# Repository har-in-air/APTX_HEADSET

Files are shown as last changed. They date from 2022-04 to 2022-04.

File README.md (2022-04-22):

# APTX_HEADSET

Kicad [schematic](aptx_headset.pdf) and PCB layout for an APTX bluetooth audio headset.
* FT-3188 Qualcomm CSR8645 module 
* OPA1664 opamps for differential to single-ended audio conversion, and headphone buffer.
* LM358 buffered virtual ground for single-ended opamp power supply.
* Two layers, 65 mm x 32 mm.

## Top
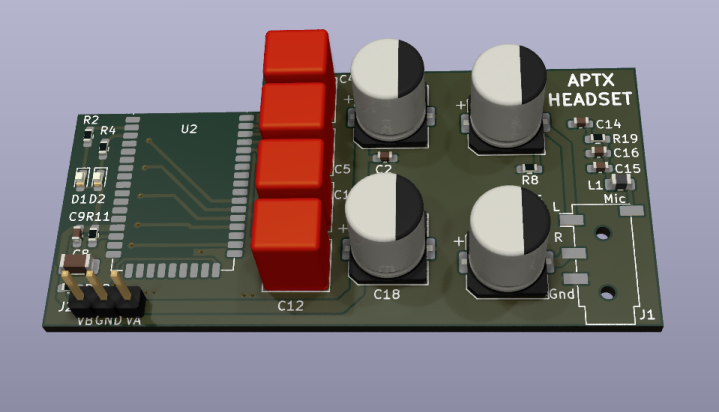
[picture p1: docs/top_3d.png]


## Bottom
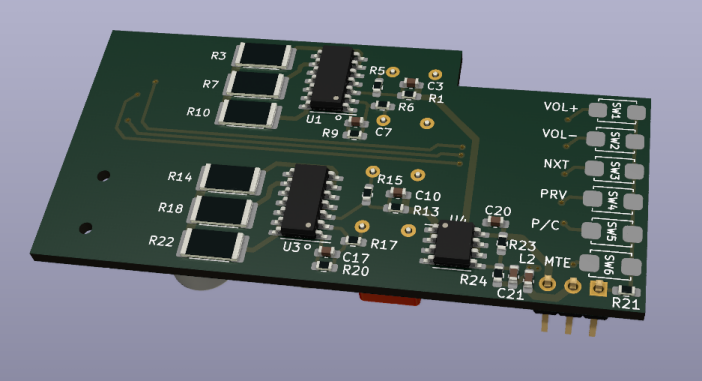
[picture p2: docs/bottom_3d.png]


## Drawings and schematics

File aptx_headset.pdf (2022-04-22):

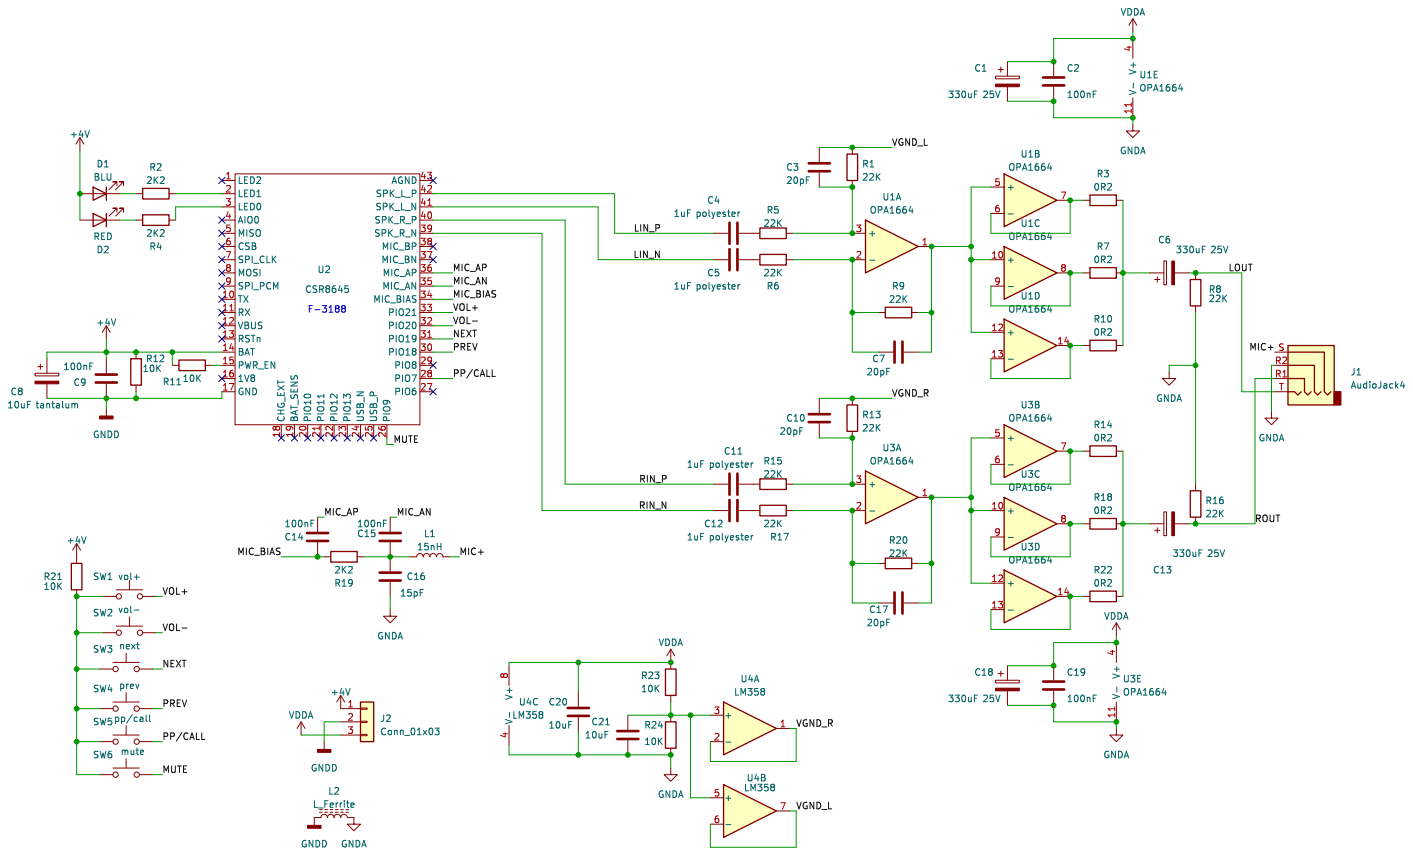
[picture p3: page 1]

4 U3E OPA1664 SW5 pp/call GNDA GNDA R21

PP/CALL MUTE NEXT VOL+ VOL-

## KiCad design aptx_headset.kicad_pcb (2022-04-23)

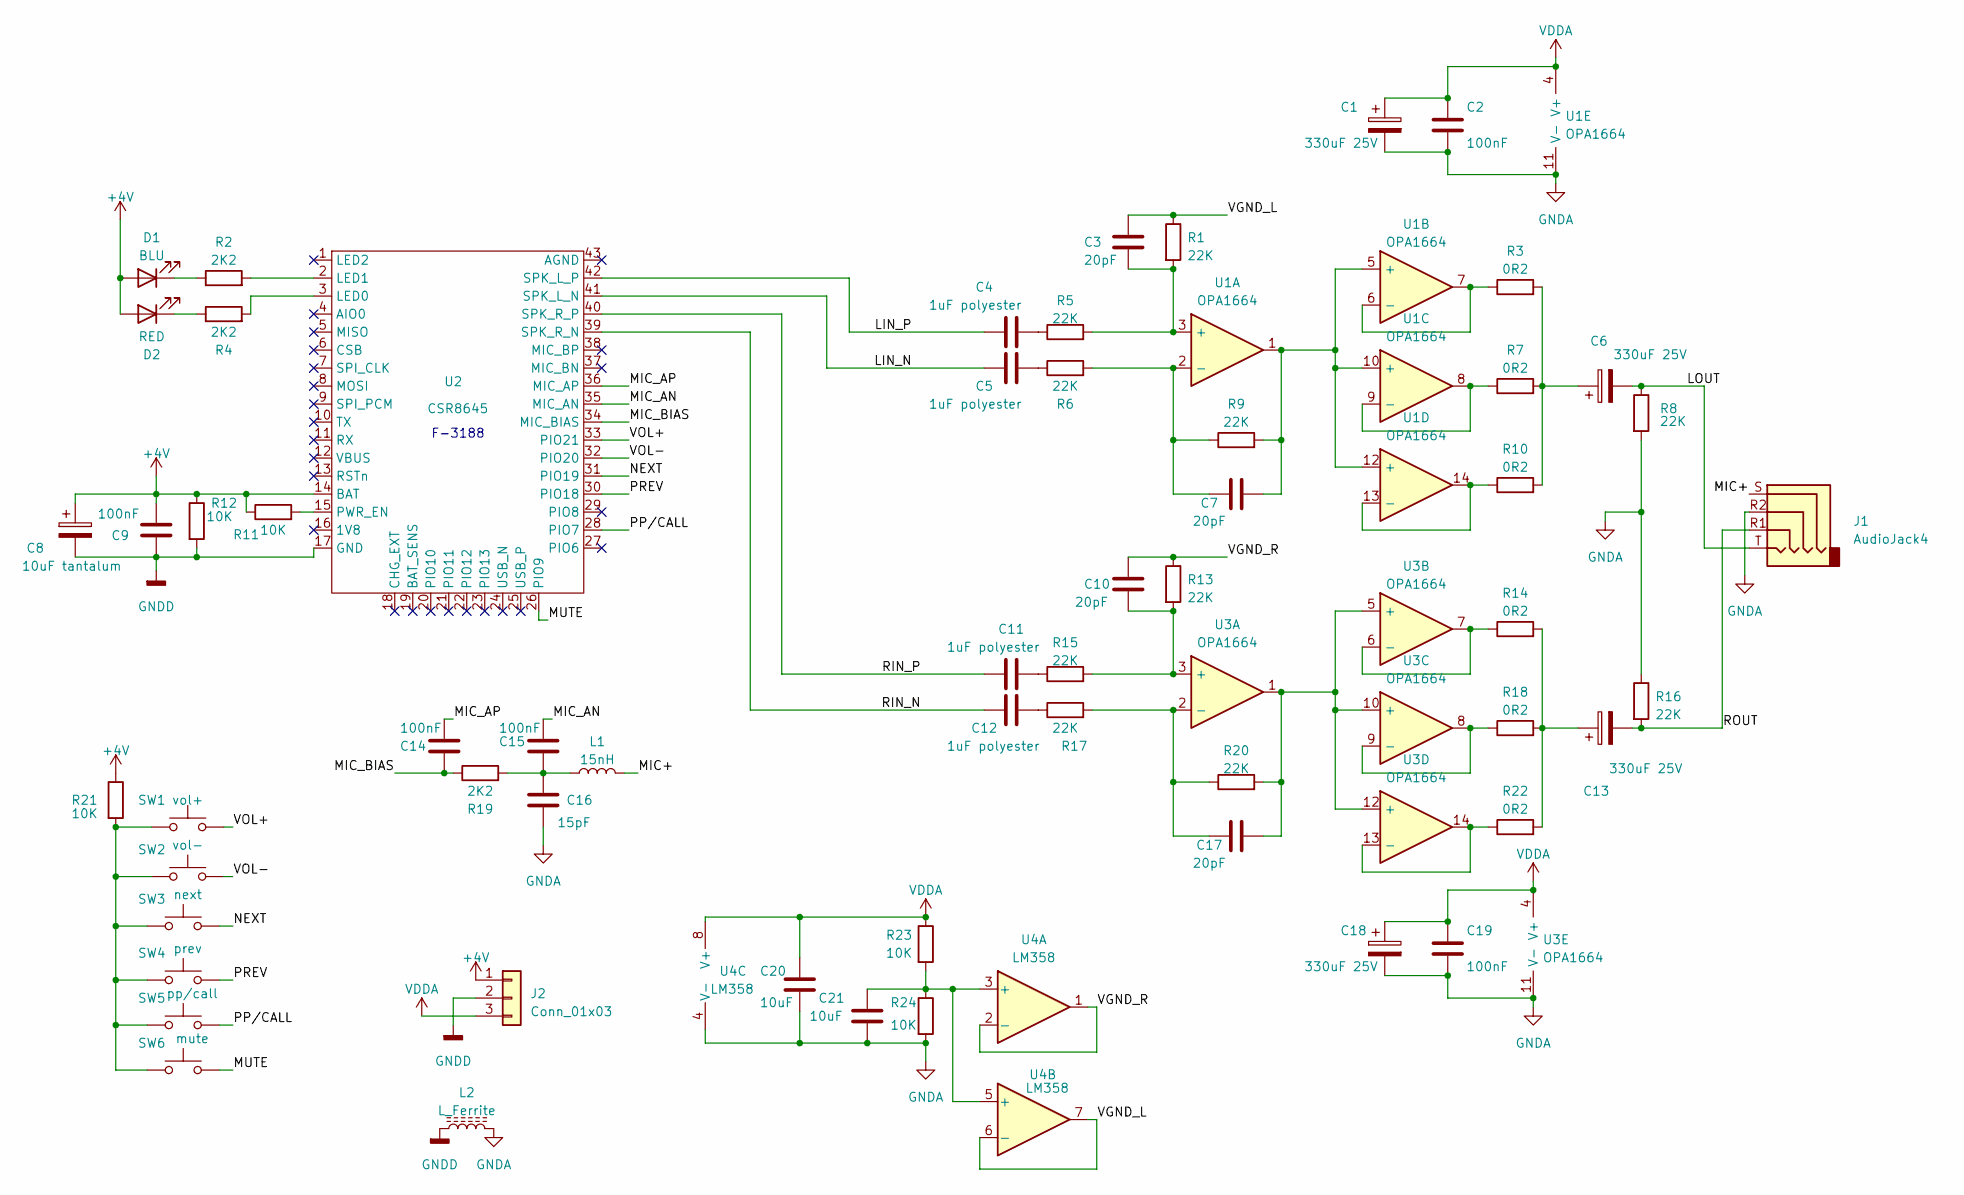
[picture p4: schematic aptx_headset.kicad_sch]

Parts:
C1, C6, C13, C18: 330uF 25V; CP_Elec_8x10
C2, C9, C14, C15, C19: 100nF; C_0603_1608Metric_Pad1.08x0.95mm_HandSolder
C3, C7, C10, C17: 20pF; C_0603_1608Metric_Pad1.08x0.95mm_HandSolder
C4, C5, C11, C12: 1uF polyester; C_Rect_L7.0mm_W6.0mm_P5.00mm
C8: 10uF tantalum; C_1206_3216Metric_Pad1.33x1.80mm_HandSolder
C16: 15pF; C_0603_1608Metric_Pad1.08x0.95mm_HandSolder
C20, C21: 10uF; C_0603_1608Metric_Pad1.08x0.95mm_HandSolder
D1: BLU; LED_0603_1608Metric_Pad1.05x0.95mm_HandSolder
D2: RED; LED_0603_1608Metric_Pad1.05x0.95mm_HandSolder
J1: AudioJack4; Jack_3.5mm_PJ320D_Horizontal
J2: Conn_01x03; PinHeader_1x03_P2.54mm_Vertical
L1: 15nH; L_0805_2012Metric_Pad1.15x1.40mm_HandSolder
L2: L_Ferrite; C_0603_1608Metric_Pad1.08x0.95mm_HandSolder
R1, R5, R6, R8, R9, R13, R15, R16, R17, R20: 22K; R_0603_1608Metric_Pad0.98x0.95mm_HandSolder
R2, R4, R19: 2K2; R_0603_1608Metric_Pad0.98x0.95mm_HandSolder
R3, R7, R10, R14, R18, R22: 0R2; R_2512_6332Metric_Pad1.40x3.35mm_HandSolder
R11, R12, R21, R23, R24: 10K; R_0603_1608Metric_Pad0.98x0.95mm_HandSolder
SW1: vol+; SW_Push_SPST_NO_Alps_SKRK
SW2: vol-; SW_Push_SPST_NO_Alps_SKRK
SW3: next; SW_Push_SPST_NO_Alps_SKRK
SW4: prev; SW_Push_SPST_NO_Alps_SKRK
SW5: pp/call; SW_Push_SPST_NO_Alps_SKRK
SW6: mute; SW_Push_SPST_NO_Alps_SKRK
U1, U3: OPA1664; SOIC-14_3.9x8.7mm_P1.27mm
U2: CSR8645; csr8645_f3188
U4: LM358; SOIC-8_3.9x4.9mm_P1.27mm

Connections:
+4V: C8.1, C9.2, D1.2 (A), D2.2 (A), J2.1, R11.1, R12.1, R21.1, U2.14 (BAT)
/LIN_N: C5.1, U2.41 (SPK_L_N)
/LIN_P: C4.1, U2.42 (SPK_L_P)
/LOUT: C6.2, J1.T, R8.1
/MIC+: J1.S, L1.2
/MIC_AN: C15.1, U2.35 (MIC_AN)
/MIC_AP: C14.1, U2.36 (MIC_AP)
/MIC_BIAS: C14.2, R19.1, U2.34 (MIC_BIAS)
/MUTE: SW6.2, U2.26 (PIO9)
/NEXT: SW3.2, U2.31 (PIO19)
/PP/CALL: SW5.2, U2.28 (PIO7)
/PREV: SW4.2, U2.30 (PIO18)
/RIN_N: C12.1, U2.39 (SPK_R_N)
/RIN_P: C11.1, U2.40 (SPK_R_P)
/ROUT: C13.2, J1.R1, R16.2
/VGND_L: C3.1, R1.1, U4.6 (-), U4.7
/VGND_R: C10.1, R13.1, U4.1, U4.2 (-)
/VOL+: SW1.2, U2.33 (PIO21)
/VOL-: SW2.2, U2.32 (PIO20)
GNDA: C1.2, C2.2, C16.2, C18.2, C19.2, C20.2, C21.2, J1.R2, L2.2, R8.2, R16.1, R24.2, U1.11 (V-), U3.11 (V-), U4.4 (V-)
GNDD: C8.2, C9.1, J2.2, L2.1, R12.2, U2.17 (GND)
unnamed: C4.2, R5.1
unnamed: C5.2, R6.1
unnamed: C6.1, R3.2, R7.2, R10.2
unnamed: C11.2, R15.1
unnamed: C12.2, R17.1
unnamed: C13.1, R14.2, R18.2, R22.2
unnamed: C15.2, C16.1, L1.1, R19.2
unnamed: D1.1 (K), R2.1
unnamed: D2.1 (K), R4.1
unnamed: R21.2, SW1.1, SW2.1, SW3.1, SW4.1, SW5.1, SW6.1
unnamed: C3.2, R1.2, R5.2, U1.3 (+)
unnamed: C7.1, R6.2, R9.1, U1.2 (-)
unnamed: C7.2, R9.2, U1.1, U1.5 (+), U1.10 (+), U1.12 (+)
unnamed: R3.1, U1.6 (-), U1.7
unnamed: R7.1, U1.8, U1.9 (-)
unnamed: R10.1, U1.13 (-), U1.14
unnamed: R4.2, U2.3 (LED0)
unnamed: R2.2, U2.2 (LED1)
unnamed: R11.2, U2.15 (PWR_EN)
unnamed: C10.2, R13.2, R15.2, U3.3 (+)
unnamed: C17.1, R17.2, R20.1, U3.2 (-)
unnamed: C17.2, R20.2, U3.1, U3.5 (+), U3.10 (+), U3.12 (+)
unnamed: R14.1, U3.6 (-), U3.7
unnamed: R18.1, U3.8, U3.9 (-)
unnamed: R22.1, U3.13 (-), U3.14
unnamed: C21.1, R23.2, R24.1, U4.3 (+), U4.5 (+)
VDDA: C1.1, C2.1, C18.1, C19.1, C20.1, J2.3, R23.1, U1.4 (V+), U3.4 (V+), U4.8 (V+)

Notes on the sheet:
F-3188

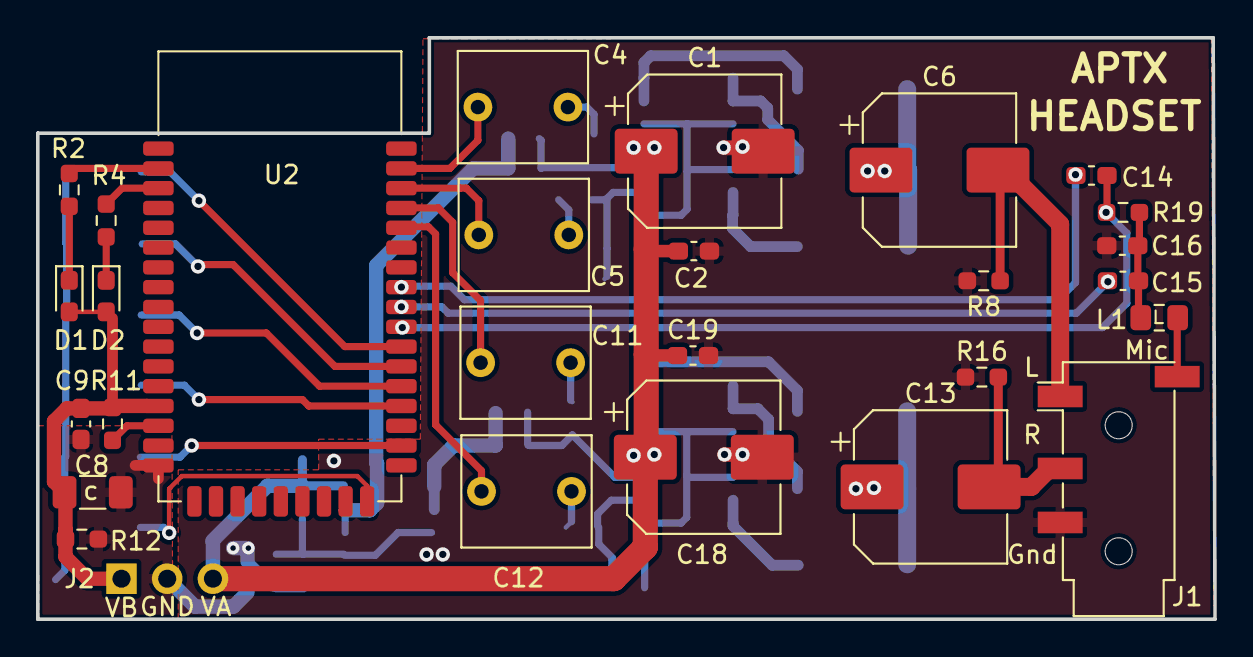
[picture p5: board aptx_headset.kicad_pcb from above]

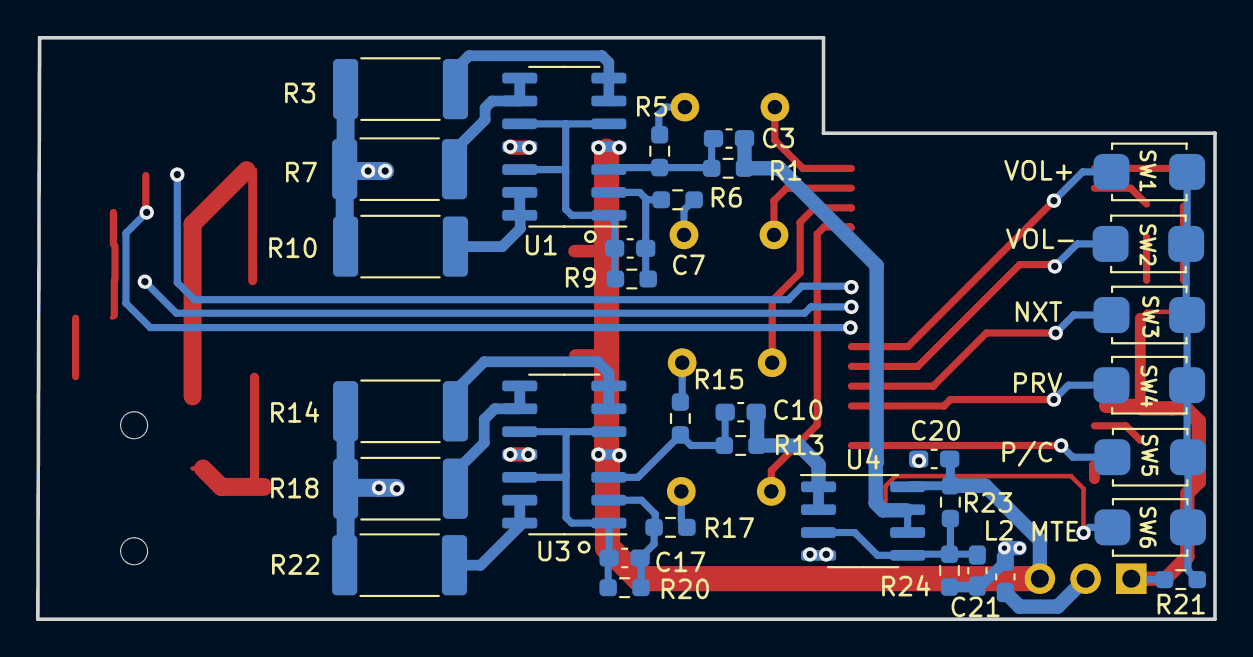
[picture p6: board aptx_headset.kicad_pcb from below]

Board: 2 copper layers, 65.4 x 32.3 mm, 61 parts (33 on the bottom side), 48 nets.

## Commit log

2022-04-22 separate buffered VGND
    [aptx_headset-B_Cu.gbl, aptx_headset-B_Mask.gbs, aptx_headset-B_Paste.gbp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]
2022-04-23 move buttons
    [aptx_headset-B_Cu.gbl, aptx_headset-B_Mask.gbs, aptx_headset-B_Paste.gbp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]
2022-04-23 move silkscreen
    [aptx_headset-B_Cu.gbl, aptx_headset-B_Mask.gbs, aptx_headset-B_Paste.gbp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]
